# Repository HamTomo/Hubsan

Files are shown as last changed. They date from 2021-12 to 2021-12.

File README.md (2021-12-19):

# Hubsan

Hubsan Notes

------------------------------------------------------------
WIP:
-----
- 
- 

------------------------------------------------------------
To Do:
-----
- How does TX/RX pair?
- What is sent over TX?
- What is sent between RX and MCU?
- What are Antennae designs?
- Layout PCBA
- Sniff points
	+ I2C line
	+ SPI line
	+ SDR
- Laptop driven TX

------------------------------------------------------------

------------------------------------------------------------
Done:
-----
- RX Schematic Drawn
- EBoM First Pass

------------------------------------------------------------

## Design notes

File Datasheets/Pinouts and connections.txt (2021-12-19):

Pinouts and connections
MINI54ZAN:

1 - voltage divider (10K from GND and 10K from VBAT) - used to detect battery voltage

2 - reset pad

3 - LED3-

4 - NC

5 - NC

6 - MC32x0 INT

7 - I2C SDA (MC32x0, MPU-3050)

8 - I2C SCL (MC32x0, MPU-3050)

9 - MPU-3050 INT

10 - NC

11 - H107: NC, H107L: A7105 CKO

12 - GND

13 - H107: unpopulated pad, H107L: LED5+

14 - MOSFET gate for motor front, left

15 - MOSFET gate for motor back, left

16 - MOSFET gate for motor back, right

17 - MOSFET gate for motor front, right

18 - H107: NC, H107L, LED6+

19 - SWDCLK

20 - SWDIO

21 - NC

22 - NC

23 - NC

24 - LED4-

25 - NC

26 - NC

27 - H107: VREG, H107L: NC

28 - VREG

29 - A7105 GIO1

30 - A7105 SDIO

31 - A7105 SCK

32 - A7105 SCS

The two LEDs on the PCB are connected in parallel with LED3 and LED4 respectively.

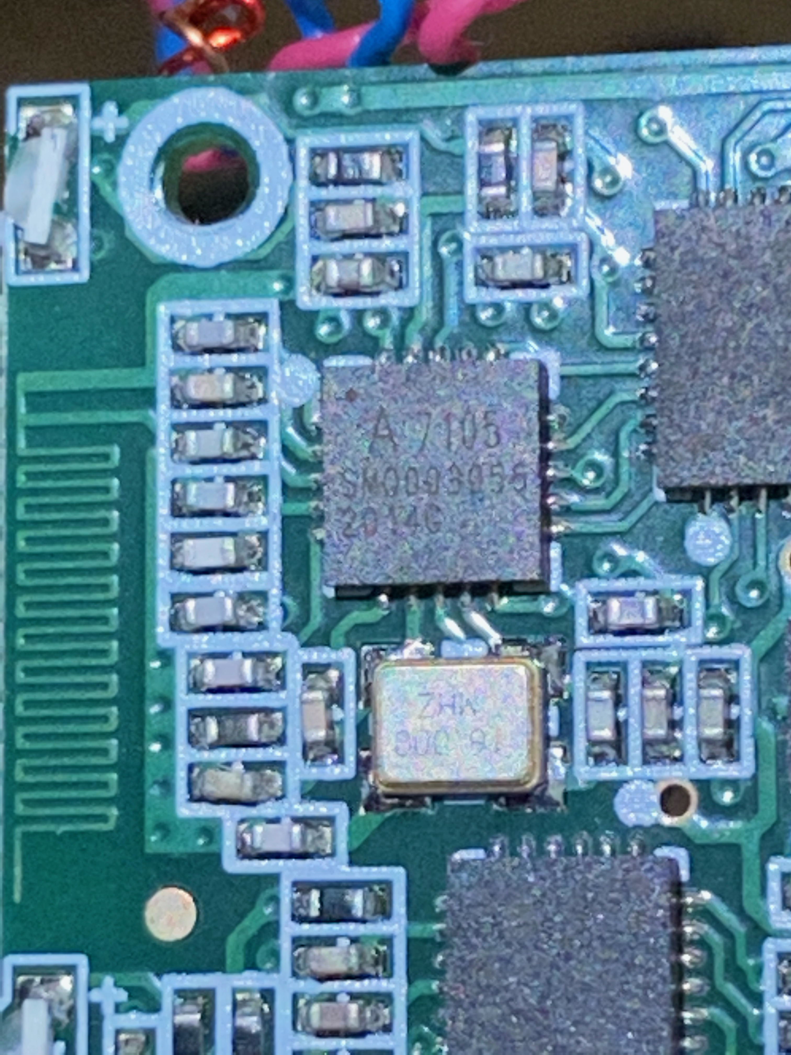
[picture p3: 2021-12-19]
104L/IMG_3495D.JPG

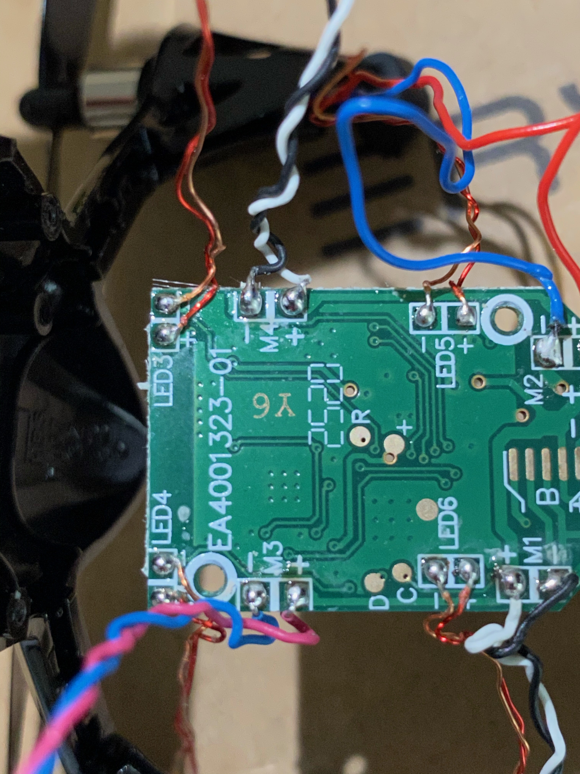
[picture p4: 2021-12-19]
104L/IMG_3497D.JPG

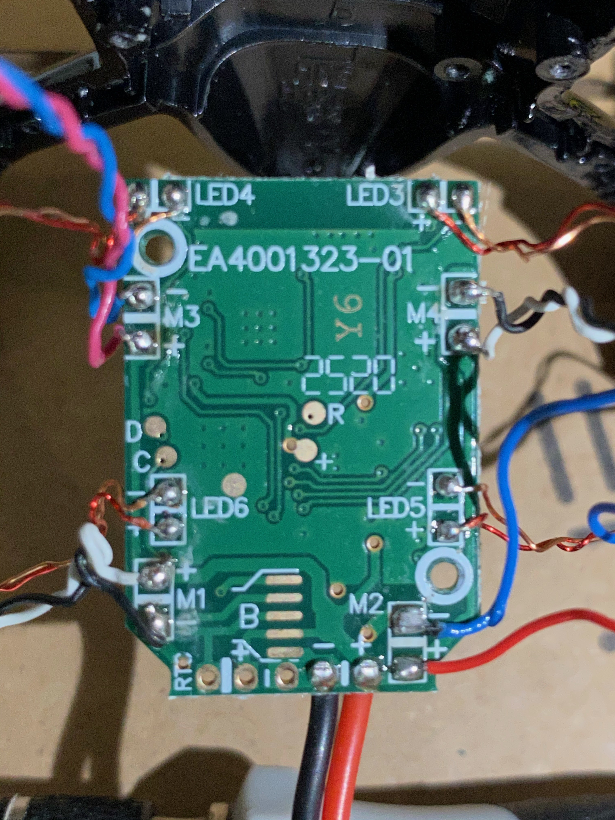
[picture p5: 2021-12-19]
104L/IMG_3499D.JPG

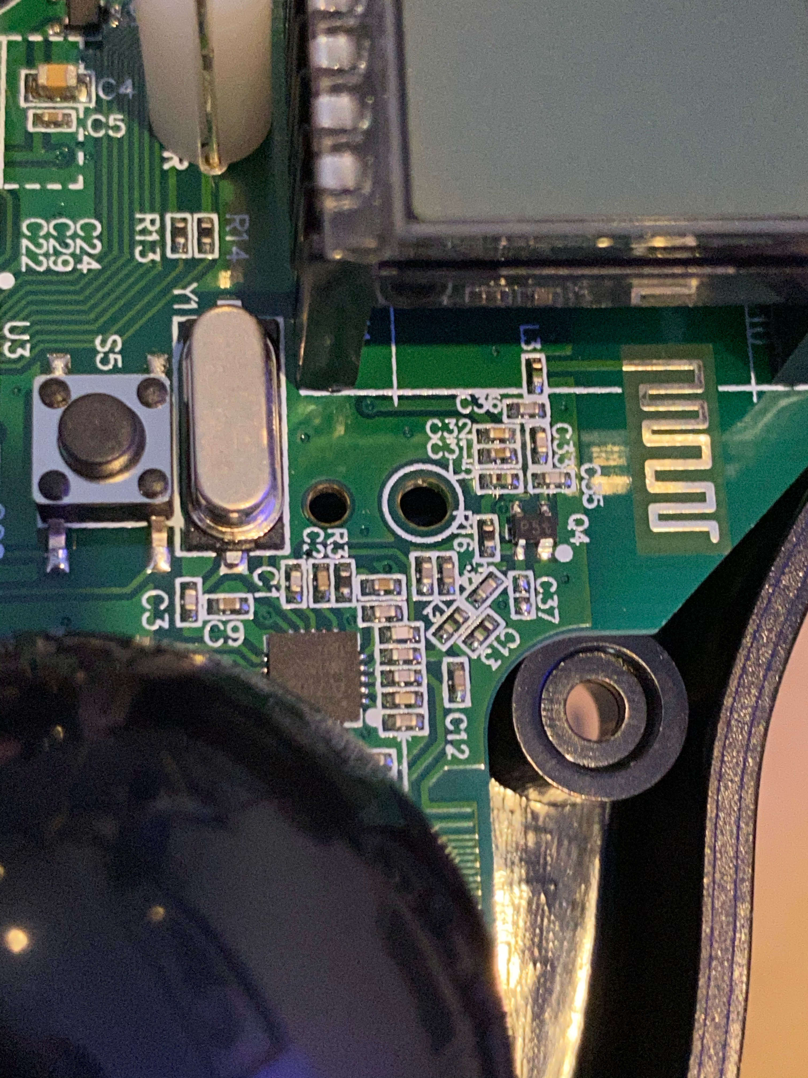
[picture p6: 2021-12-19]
TX/IMG_3471D.JPG

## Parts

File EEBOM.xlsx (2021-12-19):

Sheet: EE BoM
Designator | Package | Topmark | Part Number | Standardised | Dims | Measured
D1 |  | LED
D2 |  | LED
R1 |  |  | 10 | 10
R2 |  |  | 10 | 10
R3 |  |  | 100 | 100
R4 |  |  | 4.7k | 4.7k
R5 |  |  | 10.16k | 10k
R6 |  |  | 10.2k | 10k
R7 |  |  | 4.7k | 4.7k
R8 |  |  | 100? | 100
R9 |  |  | 201.1 | 200
R10 |  |  | 10k | 10k
R11 |  |  | 4.7k | 4.7k
R12 |  |  | 10.1 | 10
R13 |  |  | 10 | 10
R14 |  |  | 4.7k | 4.7k
R15 |  |  | 4.7k | 4.7k
R16 |  |  | 11 | 11
R17 |  |  | 10.2 | 10
R18 |  |  | 10.1 | 10
R19 |  |  | 4.7k | 4.7k
C1 |  | - | 0.120uF | 120nF
C2 |  | - | 0.120uF | 120nF
C3 |  | - | 0.120uF | 120nF
C4 |  | - | 1.2uf | 1.2uF
C5 |  | - | 0.12uF | 120nF
C6 |  | - | 0.12uF | 120nF
C7 |  | - | 0.4n? | 400pF
C8 |  | - | ? | ?
C9 |  | - | 0.3n | 300pF | 1x0.4
C10 |  | - | 0.3n | 300pF
L1 |  |  | ? | ?
C12 |  | - | 0.4n | 400pF
C13 |  | - | 1.2uF | 1.2uF
C14 |  | - | 0.3n | 300pF
C15 |  | - | 0.121uF | 120nF
C16 |  | - | 1n | 1nF
L2 |  |  | Ind | ?
C18 |  | - | 0.12uF | 120nF
C19 |  | - | 0.128uF | 120nF
C20 |  | - | 10.65nF | 11nF
C21 |  | - | 0.3n | 300pF
C22 |  | - | 10.8uF | 11uF
C23 |  | - | 0.12uF | 120nF | C30
C24 |  | - | 10.5nF | 11nF
C25 |  | - | 0.115uF | 120nF | C30
C26 |  | - | 0.120uF | 120nF
C27 |  | - | 0.120uF | 120nF
C28 |  | - | 2.75nF | 3nF |  |  | mtn2310n3_cystek
C29 |  | - | 11.1uF | 11uF | 2x1.2
C30 |  | - | 0.117uf | 120nF | ?x0.4
Q1 |  | 2310 | MTN2310N3
Q2 |  | 2310 | MTN2310N3
Q3 |  | 2310 | MTN2310N3
Q4 |  | 2310 | MTN2310N3
Q5 | SOT23-3 | dCSG | XC6206P302MR IC, POS VOLT REG, 0.3A, 3.0V, SOT23-3
U1 |  | HL016Z 706GB 2650B030 -ZY | Nuvoton
U2 |  | A 7105 SMQ003056 2014G
U3 |  | 3213B0 4B329D 521C1 | Accelerometer MC3210
U4 | QFN | INVENSENSE MPU-6050 | MPU-6050 Gyro
X1
J1
J2
D3 |  | LED
D4 |  | LED
D5 |  | LED
D6 |  | LED
M1
M2
M3
M4
J3
J4

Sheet: Measured
# | Type | Qty | Value |  | Package | Dims
#7 | Capacitor |  | ?F | ?F | 0402 |  |  | 10 | ?
#14 | Capacitor | x7 | 0.112uF | 110nF | 0402 |  | Y | 10 | ?
#6 | Capacitor | x7 | 102nF | 100nF | 0402 |  | Y | 10 | ?
 | Capacitor |  | 102nF | 100nF | 0402 |  | Y | 10 | 300pF | 35pF
 | Capacitor |  | 102nF | 100nF | 0402 |  | Y | 10 | 300pF | 40pF
 | Capacitor |  | 103nF | 100nF | 0402 |  | Y | 10 | 300pF | 41pf
 | Capacitor |  | 103nF | 100nF | 0402 |  | Y | 11 | 300pF | 108pF
 | Capacitor |  | 104nF | 100nF | 0402 |  | Y | 100 | 400pF | 129pF
 | Capacitor |  | 104nF | 100nF | 0402 |  | Y | 100 | 400pF
 | Capacitor |  | 105nF | 110nF | 0402 |  | Y | 200 | 1nF | Y
 | Capacitor |  | 105nF | 110nF | 0402 |  | Y | 4.7k | 3nF | Y
 | Capacitor |  | 106nF | 110nF | 0402 |  |  | 4.7k | 11nF | Y
 | Capacitor |  | 107.3nF | 110nF | 0402 |  |  | 4.7k | 11nF | Y
 | Capacitor |  | 107nF | 110nF | 0402 |  |  | 4.7k | 120nF | Y
 | Capacitor |  | 108pF | 110pF | 0402 |  |  | 4.7k | 120nF | Y
#15 | Capacitor | x2 | 10nF | 10nF | 0402 |  | Y | 4.7k | 120nF | Y
 | Capacitor |  | 10nF | 10nF | 0402 |  | Y | 10k | 120nF | Y
#8 | Capacitor | x1 | 10uF | 10uF | 0402 |  | Y | 10k | 120nF | Y
#2 | Capacitor | x1 | 11.62uF | 12uF | 0805 |  | Y | 10k | 120nF | Y
#11 | Capacitor | x1 | 129pF | 130pF | 0402 |  |  |  | 120nF | Y
#16 | Capacitor | x1 | 1nF | 1nF | 0402 |  | Y |  | 120nF | Y
#19 | Capacitor | x2 | 1uF | 1uF | 0402 |  | Y |  | 120nF | Y
 | Capacitor |  | 1uF | 1uF | 0402 |  | Y |  | 120nF | Y
#27 | Capacitor | x1 | 2.3nF | 2.2nF | 0402 |  | Y |  | 1.2uF | Y
#12 | Capacitor | x1 | 35pF | 36pF | 0402 |  |  |  | 1.2uF | Y
#1 | Capacitor | x3 | 38pF | 39pF | 0402 | 1mmx0.5mm |  |  | 11uF | Y
 | Capacitor |  | 40pF | 39pF | 0402 |  |  |  | 11uF | Y
 | Capacitor |  | 41pF | 39pF | 0402 |  |  |  | 120uF
#1 | Crystal | x1 | 16.000MHz |  |  | 3.2x2.5 |  |  | 120uF
#1 | Diode | x2 | LED |  |  | 2.2x0.5 | Uz=2.68V |  | 120uF
#1 | IC | x1 | TX
#2 | IC | x1 | Gyro
#3 | IC | x1 | Acc
#1 | Inductor | x1 | ? |  | 0402
#1 | LDO | x1 | +3V
#1 | MCU | x1 | MCU
#1 | Resistor | x7 | 10R | 10R | 0402
 | Resistor |  | 10R | 10R | 0402
#3 | Resistor | x6 | 4752R | 4.7kR | 0402
 | Resistor |  | 4734R | 4.7kR | 0402 | 1x0.5
 | Resistor |  | 4793R | 4.7kR | 0402
 | Resistor |  | 4.68kR | 4.7kR | 0402
 | Resistor |  | 4.68kR | 4.7kR | 0402
 | Resistor |  | 10R | 10R | 0402
 | Resistor |  | 10R | 10R | 0402
 | Resistor |  | 4.7kR | 4.7kR | 0402
#11 | Resistor | x3 | 10kR | 10kR | 0402
 | Resistor |  | 10kR | 10kR | 0402
#13 | Resistor | x2 | 100R | 100R | 0402
 | Resistor |  | 10R | 10R | 0402
 | Resistor |  | 10R | 10R | 0402
 | Resistor |  | 10R | 10R | 0402
#17 | Resistor | x1 | 200R | 200R | 0402
 | Resistor |  | 10.2kR | 10kR | 0402
 | Resistor |  | 100R | 100R | 0402
 | Transistor | x4 | N Channel

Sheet: Mesured LCR
0.14uH
4.681kO
9.9O
100O
4.7k
10.1
100
4.7k
10
10k
10
10
4.7k
10
4.7k
10
4.7k
10k

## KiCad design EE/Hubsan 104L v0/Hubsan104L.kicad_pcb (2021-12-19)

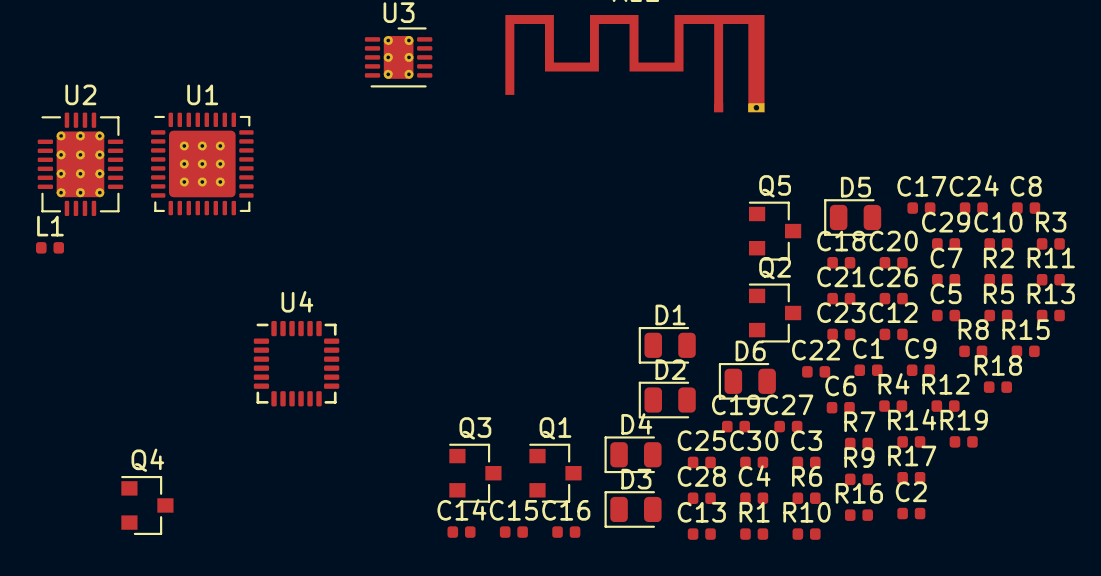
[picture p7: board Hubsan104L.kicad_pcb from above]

Board: 2 copper layers, 65 parts (0 on the bottom side), 50 nets, no tracks yet.

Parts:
AE1: Antenna; Texas_SWRA117D_2.4GHz_Left
C1, C2, C3, C5, C6, C15, C18, C19, C23, C25, C26, C27, C30: 100nF; C_0402_1005Metric
C4, C13: 1uF; C_0402_1005Metric
C7: 120pF; C_0402_1005Metric
C8: 1.5nF; C_0402_1005Metric
C9: 27pF; C_0402_1005Metric
C10: 12pF; C_0402_1005Metric
C12: 100pF; C_0402_1005Metric
C14: 10pF; C_0402_1005Metric
C16: 680pF; C_0402_1005Metric
C17, C21: 33pF; C_0402_1005Metric
C20, C24: 10nF; C_0402_1005Metric
C22: 8.2uF; C_0402_1005Metric
C28: 2.2nF; C_0402_1005Metric
C29: 10uF; C_0402_1005Metric
D1, D2, D3, D4, D5, D6: LED_Small; LED_0805_2012Metric
L1: 130nH; L_0402_1005Metric
Q1, Q2, Q3, Q4: MTN2310N3; SOT-23
Q5: MCP1700-3002E_SOT23; SOT-23
R1, R2, R6, R12, R13, R16, R17, R18: 10; R_0402_1005Metric
R3: 100; R_0402_1005Metric
R4, R7, R11, R14, R15, R19: 4.7k; R_0402_1005Metric
R5, R8, R10: 10k; R_0402_1005Metric
R9: 200; R_0402_1005Metric
U1: Nuvoton_MINI54ZAN_MCU; QFN-32-1EP_5x5mm_P0.5mm_EP3.7x3.7mm_ThermalVias
U2: Amicom_A7105_TX; QFN-20-1EP_4x5mm_P0.5mm_EP2.65x3.65mm_ThermalVias
U3: MC3210; DFN-10-1EP_3x3mm_P0.5mm_EP1.65x2.38mm_ThermalVias
U4: MPU-6050; InvenSense_QFN-24_4x4mm_P0.5mm

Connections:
+3V0: C1.2, C2.2, C19.1, C29.2, Q5.2, R1.1, R2.1, R12.2, R13.1, R16.1, R17.2, R18.1, U1.28, U2.19, U3.10
+BATT: C3.1, C6.1, C22.1, C25.1, C30.2, Q5.3, R10.2
/B: C21.1, U2.8
/D: C17.1, U2.9
/GYRO_INT: U1.9, U4.12
/INTN: U1.6, U3.5
/LED1_4: D1.1, D4.1, U1.24
/LED2_3: D2.1, D3.1, U1.3
/LED5: R6.2, U1.13
/LED6: R3.2, U1.18
/MOTOR1: Q2.1, R7.1, U1.16
/MOTOR2: Q3.1, R11.1, U1.15
/MOTOR3: Q1.1, R4.1, U1.17
/MOTOR4: Q4.1, R14.1, U1.14
/TX_CKO: R5.1, U2.18
/U1_1: C15.2, R8.1, R10.1, U1.1
/U1_SCL: R19.1, U1.8, U3.7, U4.23
/U1_SDA: R15.1, U1.7, U3.8, U4.24
GND: C1.1, C2.1, C4.1, C5.1, C7.1, C8.1, C12.2, C13.2, C14.2, C15.1, C16.2, C17.2, C18.2, C19.2, C20.2, C21.2, C22.2, C23.2, C24.2, C26.2, C27.1, C28.1, C29.1, D5.1, D6.1, Q1.3, Q2.3, Q3.3, Q4.3, Q5.1, R4.2, R7.2, R8.2, R11.2, R14.2, R15.2, R19.2, U1.12, U2.7, U2.15, U3.4, U3.9, U4.9, U4.11, U4.18
unnamed: AE1.1, C9.2, C10.2
unnamed: C3.2, Q2.2
unnamed: C5.2, U2.13
unnamed: C6.2, Q1.2
unnamed: C7.2, U2.1
unnamed: C8.2, U2.2
unnamed: C9.1, U2.3
unnamed: C10.1, L1.2, U2.4
unnamed: C4.2, C12.1, C13.1, L1.1, U2.10, U2.20
unnamed: C14.1, U2.5
unnamed: C16.1, R9.1, U2.6
unnamed: C18.1, U1.2
unnamed: C20.1, R9.2
unnamed: C23.1, R13.2, U3.3
unnamed: C24.1, R12.1, U4.8
unnamed: C25.2, Q3.2
unnamed: C26.1, U4.10
unnamed: C27.2, R18.2, U4.13
unnamed: C28.2, U4.20
unnamed: C30.1, Q4.2
unnamed: D1.2, R2.2
unnamed: D2.2, R17.1
unnamed: D3.2, R16.2
unnamed: D4.2, R1.2
unnamed: D5.2, R6.1
unnamed: D6.2, R3.1
unnamed: R5.2, U1.11
unnamed: U1.29, U2.16
unnamed: U1.30, U2.14
unnamed: U1.31, U2.12
unnamed: U1.32, U2.11
